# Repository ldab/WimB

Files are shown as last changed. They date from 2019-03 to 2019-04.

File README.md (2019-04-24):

# WimB - Where is my Bike

<p>The firmware has been writen using PlatformIO which is a nice, neat IDE, check it out:&nbsp;<a href="https://platformio.org/platformio-ide" rel="nofollow">Learn how to install PlatformIO IDE</a></p>







## Download Blynk App: [Getting Started with Blynk](https://www.blynk.cc/getting-started/)

This is a minimalist Blynk App you will **1,800 energy points**.

* Download Blynk App: [](http://j.mp/blynk_Android) [](http://j.mp/blynk_iOS)
* Touch the QR-code icon and point the camera to the code below


<p>
&nbsp;&nbsp;
</p>

* Enjoy my app!

## Content

1. [TODO](/README.md#TODO)
2. [How does it work?](/README.md#how-does-it-work)
3. [Estimated Power Consumption](/README.md#Estimated-Power-Consumption)
4. [Cellular data usage](/README.md#cellular-data-usage)
5. [SARA-R4 PWR_ON Pin](/README.md#SARA-R4-PWR_ON-Pin)
6. [SARA-R4 PSM - Power Save Mode configuration](/README.md#sara-r4-psm---power-save-mode-configuration)
7. [SERCOM and PIN mapping](/README.md#SERCOM-and-PIN-mapping)
8. [Schematic](/README.md#schematic)
9. [DataSheets](/README.md#datasheets)
10. [Enclosure](/README.md#enclosure)
11. [How to Start?](/README.md#how-to-start)
12. [Credits](/README.md#credits)

## TODO

- [x] Put device to sleep;
- [ ] Communnicate with SARA-R4
- [x] Set SARA-PSM values
- [ ] Communicate with GNSS;
- [ ] AssistNow AID for GNSS
- [x] Set interrupts on accelerometer;
- [x] Finish accelerometer lib
- [ ] Monitor SARA GPIO in order to detect modem is ready +UGPIOC
- [ ] Monitor SARA V_INT in order to detect modem ON
- [ ] Monitor GNSS *something* in order to detect GNSS awake

## How does it work?

Here you will find a simplified flowchart demonstrating how the code works: 

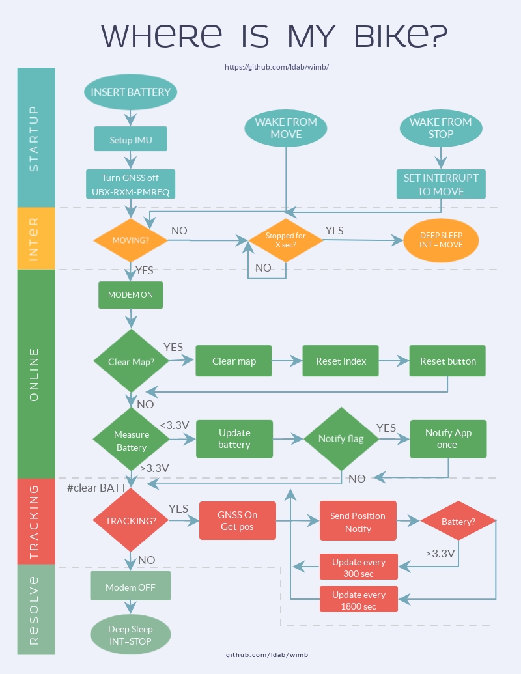
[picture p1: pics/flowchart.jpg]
Flowchart


## Estimated Power Consumption

This is hard to predict however we have the [Datasheets](./datasheet) and can roughly estimate it, we have:
* ATSAMD21E18 MCU;
* SARA-R412;
* SAM-M8Q;
* LIS3DH IMU;
* TXS0102 Level-shifter;
* SN74LVC1G07 Level-shifter;
* HT7833 LDO;
* TP4056 Battery charger;
* Battery ADC;

#### Low power - Sleeping

Arduino library set all pins as `INPUT` on `wiring.c` this result in excessive current draw, I got around 300μA on the best case scenario, turning all Clock off, VREG, and BOD33.

```
  // Setup all pins (digital and analog) in INPUT mode (default is nothing)
  for (uint32_t ul = 0 ; ul < NUM_DIGITAL_PINS ; ul++ )
  {
    pinMode( ul, INPUT ) ;
  }
```

it we change SWCLK & SWDIO to `pinMode( ul, INPUT_PULLUP ) ;` **BOOM** -> board current on sleep was spot on 48μA.

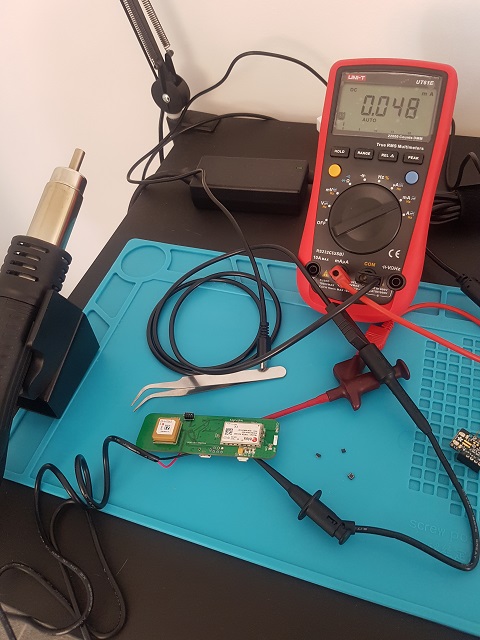
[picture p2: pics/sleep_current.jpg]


Component                 | ~TYP μA
------------------------- | ------
ATSAMD21E18 MCU           | 4
SARA-R412                 | 6
SAM-M8Q                   | 15
LIS3DH IMU                | 2
TXS0102 Level-shifter     | 2
SN74LVC1G07 Level-shifter | 5
HT7833 LDO                | Assume 10
TP4056 Battery charger    | 2
Battery ADC               | 2
TOTAL                     | 48

#### Tracking

Component                 | ~TYP μA
------------------------- | ------
ATSAMD21E18 MCU           | 4,000
SARA-R412                 | 27,200*
SAM-M8Q                   | 9,500
LIS3DH IMU                | 2
TXS0102 Level-shifter     | 14
SN74LVC1G07 Level-shifter | 5
HT7833 LDO                | Assume 10
TP4056 Battery charger    | 2
Battery ADC               | 2
TOTAL                     | ~41mA

*Current for Modem depends on the update interval, registration and signal level -> 200mA max for TX/RX @30sec to exec every 300 sec + 9mA @Active mode = 27.2mA 

## Cellular data usage

[Blynk Protocol message](https://github.com/blynkkk/blynk-server/blob/master/docs/README_FOR_APP_DEVS.md#protocol-messages)

* [Blynk HEARTBEAT](https://community.blynk.cc/t/expected-data-usage-for-hardware-connection-heartbeat-to-blynk-server/7138/16) = 5 bytes every minute;
* [Button message](https://community.blynk.cc/t/solved-gsm-data-usage/16122/2?u=ldb) = ~10 bytes
* [Data message](https://community.blynk.cc/t/blynk-electron-data-usage-extremely-high/16577/4?u=ldb) = ~14 bytes
* [TCP Overhead?](https://community.blynk.cc/t/expected-data-usage-for-hardware-connection-heartbeat-to-blynk-server/7138/16) = 20 bytes

If it connects twice a day non-active => ( Clear Map + Active? + Update Battery ) * 2 = bump it up to 80 bytes/day

Active mode running at 300 seconds => ( 5 * Heartbeat + Active? + Update Battery + Send location )* 12 = 800 bytes/hour

## SARA-R4 PWR_ON Pin

Low  level  on  the PWR_ON pin,  which  is  normally  set  high  by  an  internal  pull-up,  for  a  valid  time period  when  the applied VCCvoltage  is  within  the  valid  operating  range. The PWR_ON line has to be driven by open drain, open collector or contact switch

Parameter       |Min. |Max.  |Unit|Remarks
--------------- | --- |----- | -- | ---------------------------------------
PWR_ON low time |0.15 | 3.20 | s  | Low time to trigger module switch *ON*
PWR_ON low time |1.5  |      | s  | Low time to trigger module switch *OFF*

## SARA-R4 PSM - Power Save Mode configuration

The grant of PSM is a negotiation between SARA-R4/N4 series module and the **attached network:** the network accepts PSM  by  providing  the  actual  value  of  the  “Active  Timer”  (and  “Periodic  Update Timer”) to be used in the Attach/TAU/RAU accept procedure. The maximum duration, including the “Periodic Update Timer”, is about 413 days.  The SARA-R4/N4  series module  enters  PSM  low  power deep sleep mode only after the “Active Timer” expires

* If  the  power  saving  mode  is  enabled  (+CPSMS:  1),  everything  on  the  device  will  power  down  except  thereal-time clock (RTC) after the expiry of T3324 (Active Time). It will stay powered down until the expiry ofT3412 (Extended TAU Timer) or if the Power On line is toggled.
* If the power saving mode is disabled (+CPSMS: 0), the device will not enter Power Save Mode (PSM)

#### Requested_Periodic_TAU - PSM total duration

```
Bits 5 to 1 represent the binary coded timer value.
Bits 6 to 8 defines the timer value unit for the GPRS timer:
8 7 6 
0 0 0 value is incremented in multiples of 10 minutes
0 0 1 value is incremented in multiples of 1 hour
0 1 0 value is incremented in multiples of 10 hours
0 1 1 value is incremented in multiples of 2 seconds
1 0 0 value is incremented in multiples of 30 seconds
1 0 1 value is incremented in multiples of 1 minute
1 1 0 value is incremented in multiples of 320 hours
1 1 1 value indicates that the timer is deactivated.
```

**The requested extended periodic TAU value(T3412) iscoded as one byte (octet 3) of the GPRS Timer 3 information element coded as bitformat (e.g. "10100001" equals 1 minute).  see the GPRS Timer 3 IE in 3GPP TS 24.008 Table10.5.163a/3GPP TS 24.008 - page 669**

#### Requested_Active_Time - Active/Paging time

```
Bits 5 to 1 represent the binary coded timer value.
Bits 6 to 8 defines the timer value unit for the GPRS timer as follows:
Bits
8 7 6
0 0 0  value is incremented in multiples of 2 seconds
0 0 1  value is incremented in multiples of 1 minute
0 1 0  value is incremented in multiples of decihours
1 1 1  value indicates that the timer is deactivated.

Other values shall be interpreted as multiples of 1 minute in this version of the protocol. 
```

**Requested Active Time value (T3324) iscoded as one byte (octet 3) of the GPRS Timer 2 information element coded as bitformat (e.g. "00100100" equals 4 minutes).  see the GPRS Timer 2 IE in 3GPP TS 24.008 Table10.5.163/3GPP TS 24.008 - page 668**

## SERCOM and PIN mapping

PIN mapping and re-assignment are required since we need 3x UART and unfortunatelly Adafruit Trinket M0 did not use the same combination as we needed/wanted.

Those changes are made on the `variant.h` and `variant.cpp` found on your installation directory `.platformio\packages\framework-arduinosam\variants\trinket_m0`.

On the `.cpp` file we comment the `Serial1` definition as `SERCOM0` will be used by the I2C interface:
https://github.com/ldab/WimB/blob/5da6a90e527ac1eb7648ca4fd2846885c14b10b4/board_variant/variant.cpp#L97-L102

The `.h` file we define `SERCOM0` as the interface for I2C, as well different PIN because of `SERCOM` and `SERCOM_ALT` definition
https://github.com/ldab/WimB/blob/5da6a90e527ac1eb7648ca4fd2846885c14b10b4/board_variant/variant.h#L142-L145

## Schematic

* The Schematics provided here are provided "as it is" and no guarantee is given as it does not follow the supplier specifications especially on the antenna design:

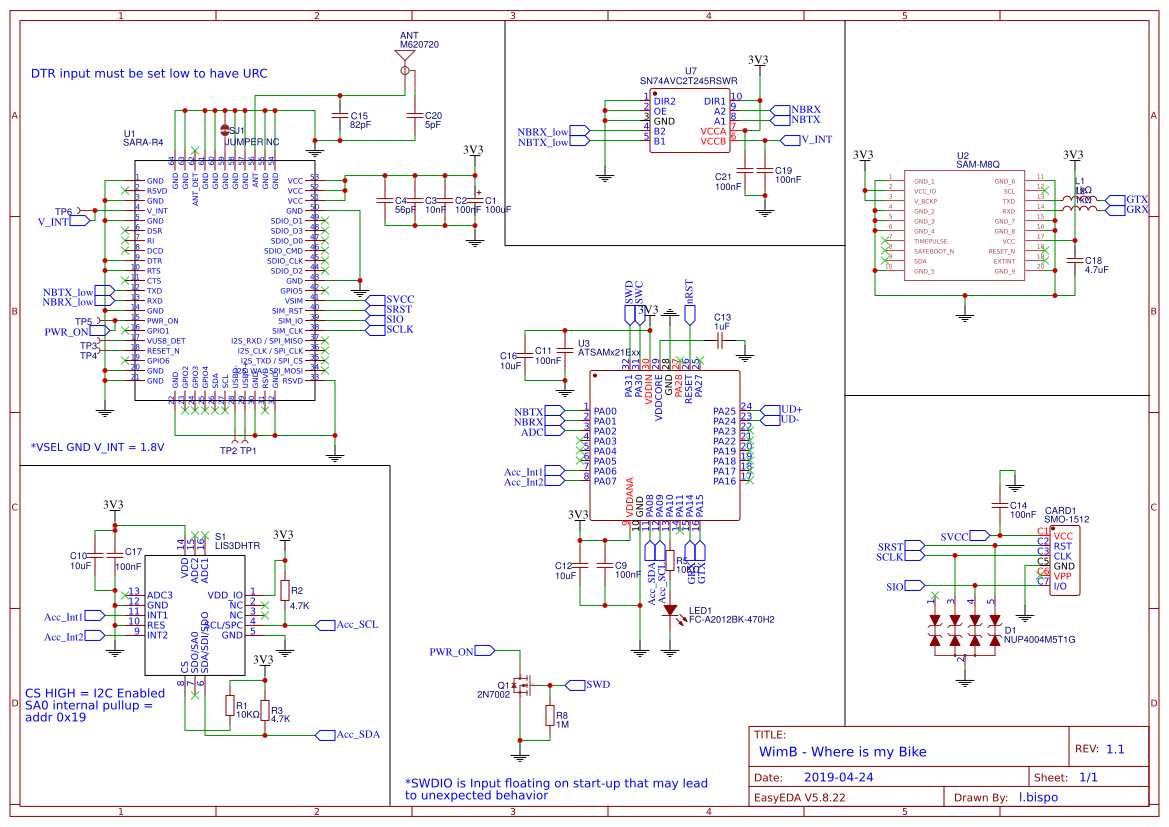
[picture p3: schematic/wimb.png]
Schematic page 1

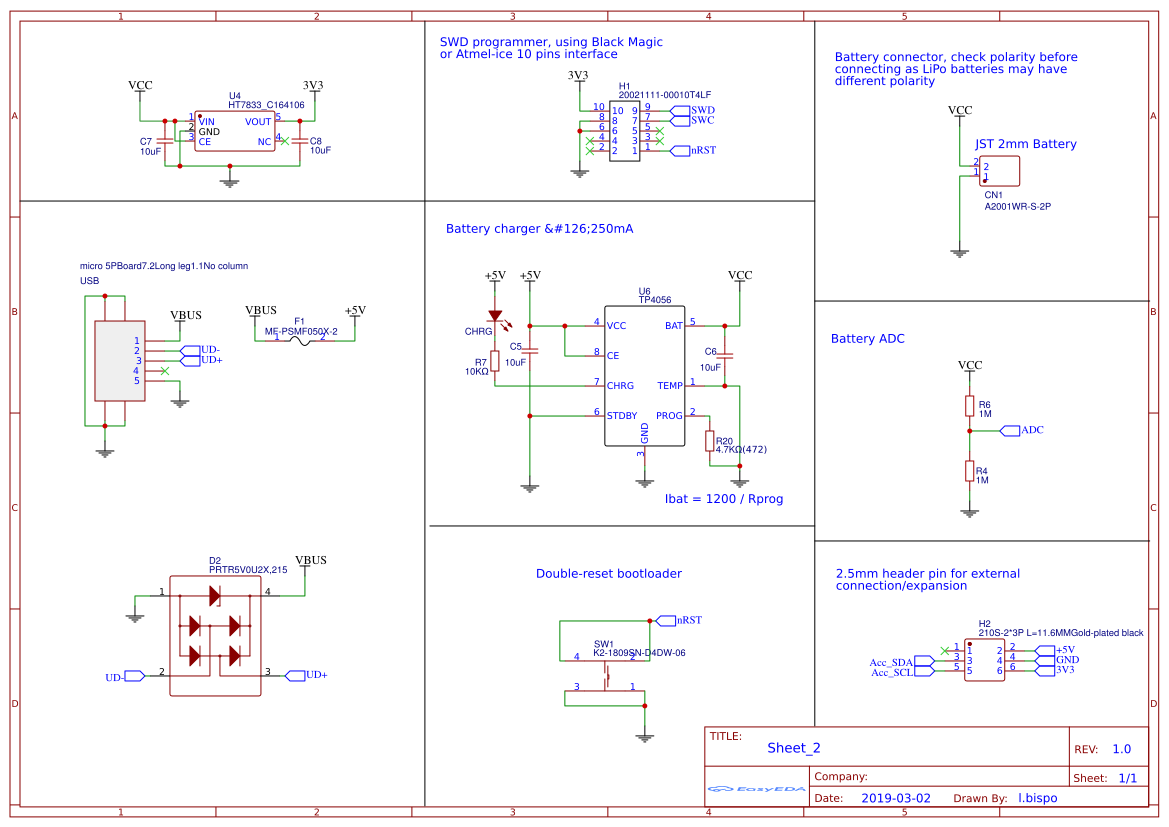
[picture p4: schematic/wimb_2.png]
Schematic page 2


## Datasheets

You can find technical information here: [datasheets](./datasheet)

## Enclosure

A 3D print file for the enclosure is also available (untestest/not printed) [here](./3DPrint%20Enclosure).

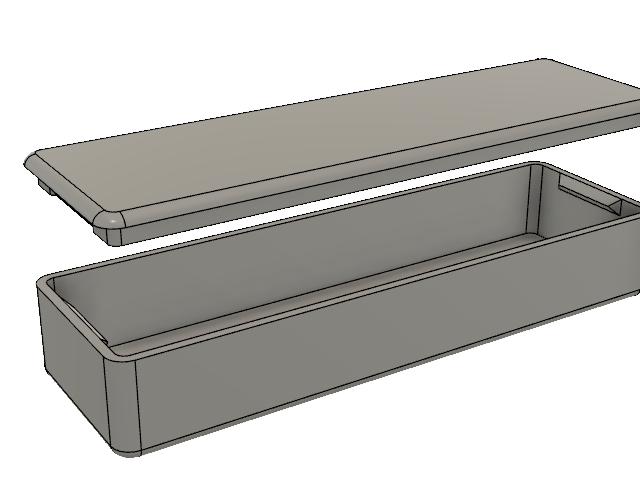
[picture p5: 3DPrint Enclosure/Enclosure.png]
enclosure


## How to start?

## Credits

Github Shields and Badges created with [Shields.io](https://github.com/badges/shields/)

Flowchart made with [VISME](https://www.visme.co/)

3D Design inspired by [Adafruit Youtube video](https://www.youtube.com/watch?v=VVmOtM60VWw) using [Autodesk Fusin 360](https://www.autodesk.com/products/fusion-360/overview)

Icons made by [Smashicons](https://www.flaticon.com/authors/smashicons) from [Flaticon](www.flaticon.com) is licensed by Creative Commons BY 3.0 [CC BY 3.0](https://creativecommons.org/licenses/by/3.0/)

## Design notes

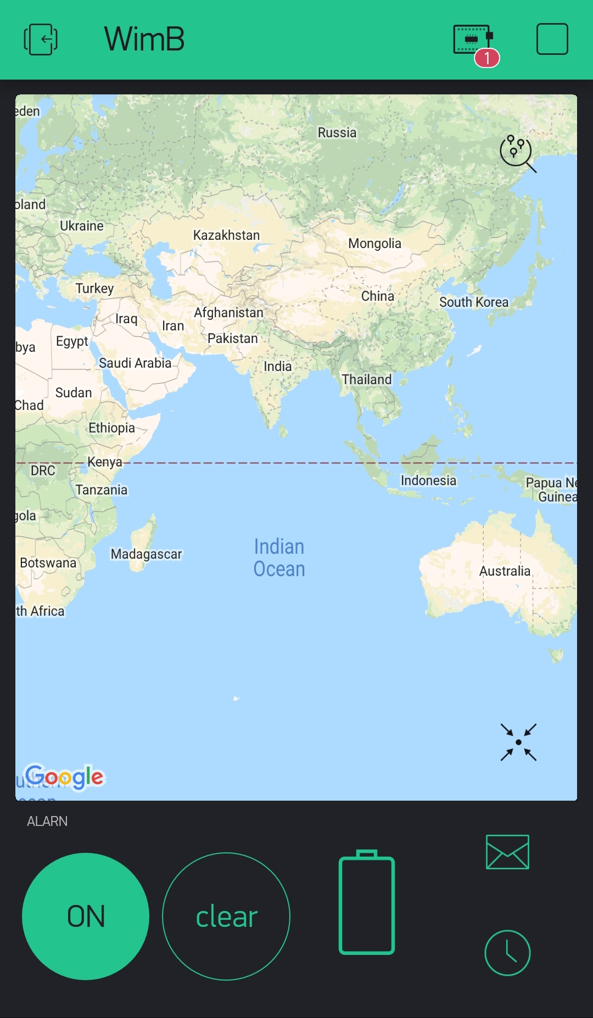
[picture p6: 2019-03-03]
pics/App_Blynk.jpg

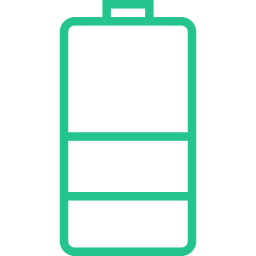
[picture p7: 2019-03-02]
pics/battery_50.png

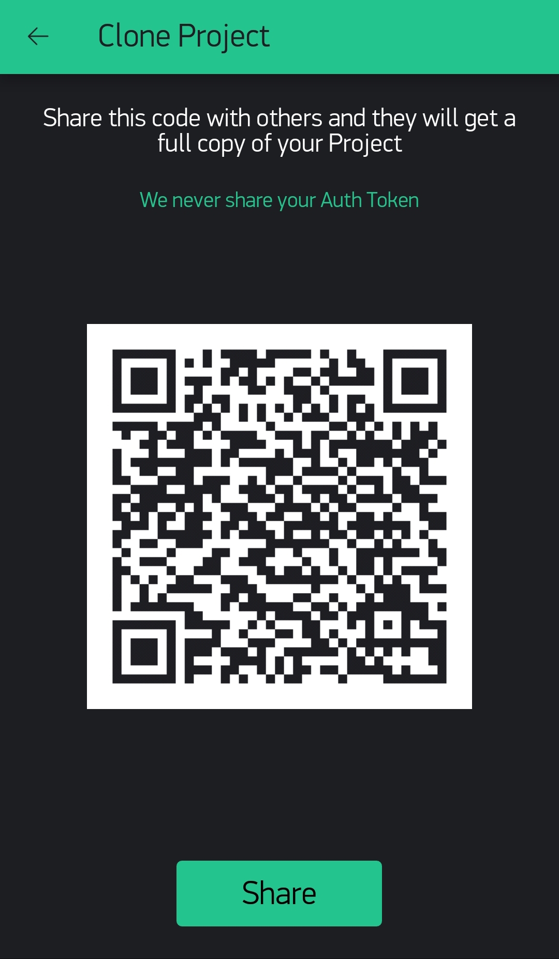
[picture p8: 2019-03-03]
pics/QR_Blynk.jpg

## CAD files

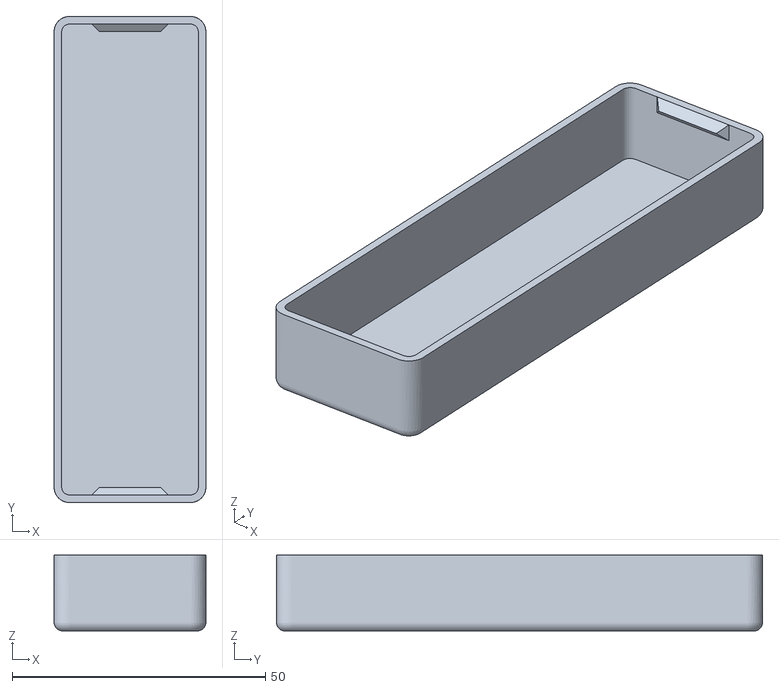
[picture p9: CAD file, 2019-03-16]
3DPrint Enclosure/case.stl
30.0 x 96.0 x 15.0

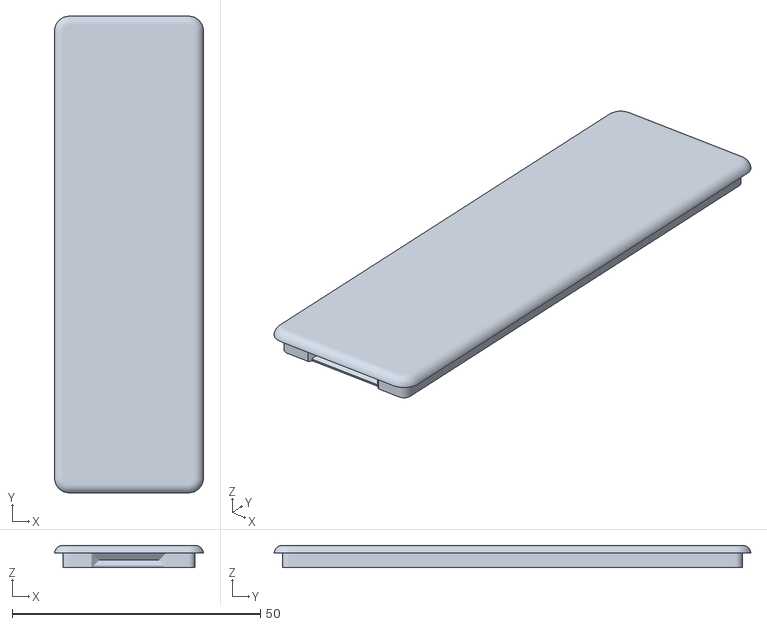
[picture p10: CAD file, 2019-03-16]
3DPrint Enclosure/cover.stl
30.0 x 96.0 x 4.50

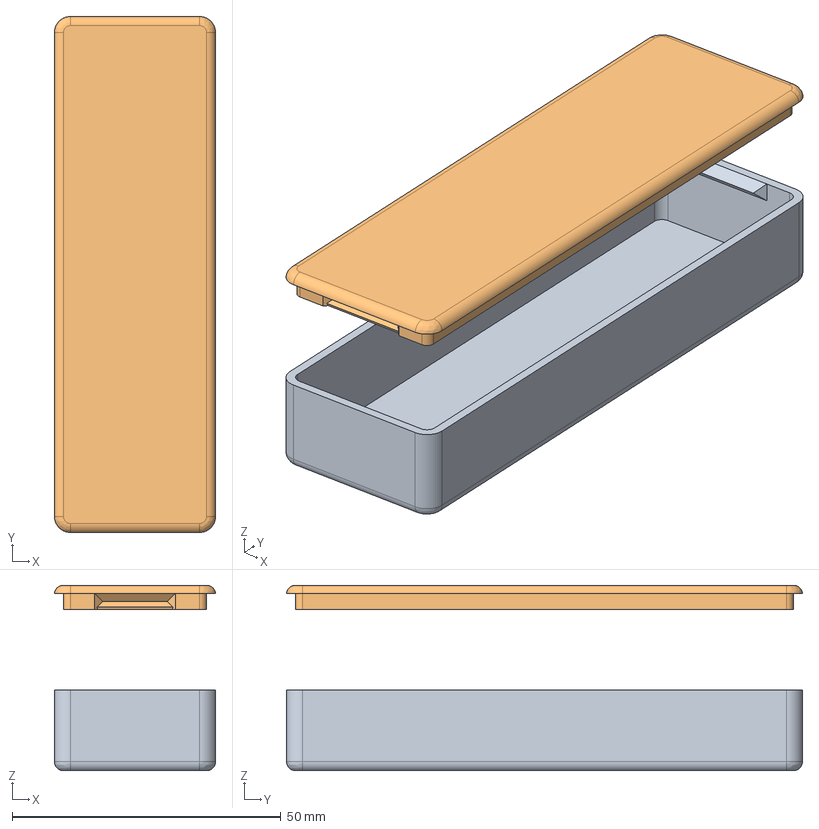
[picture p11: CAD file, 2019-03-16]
3DPrint Enclosure/Enclosure.step
30.0 x 96.0 x 34.5 mm
Case
Cover

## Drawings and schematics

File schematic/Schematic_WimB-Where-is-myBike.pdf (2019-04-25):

3V3
3V3 | 3V3

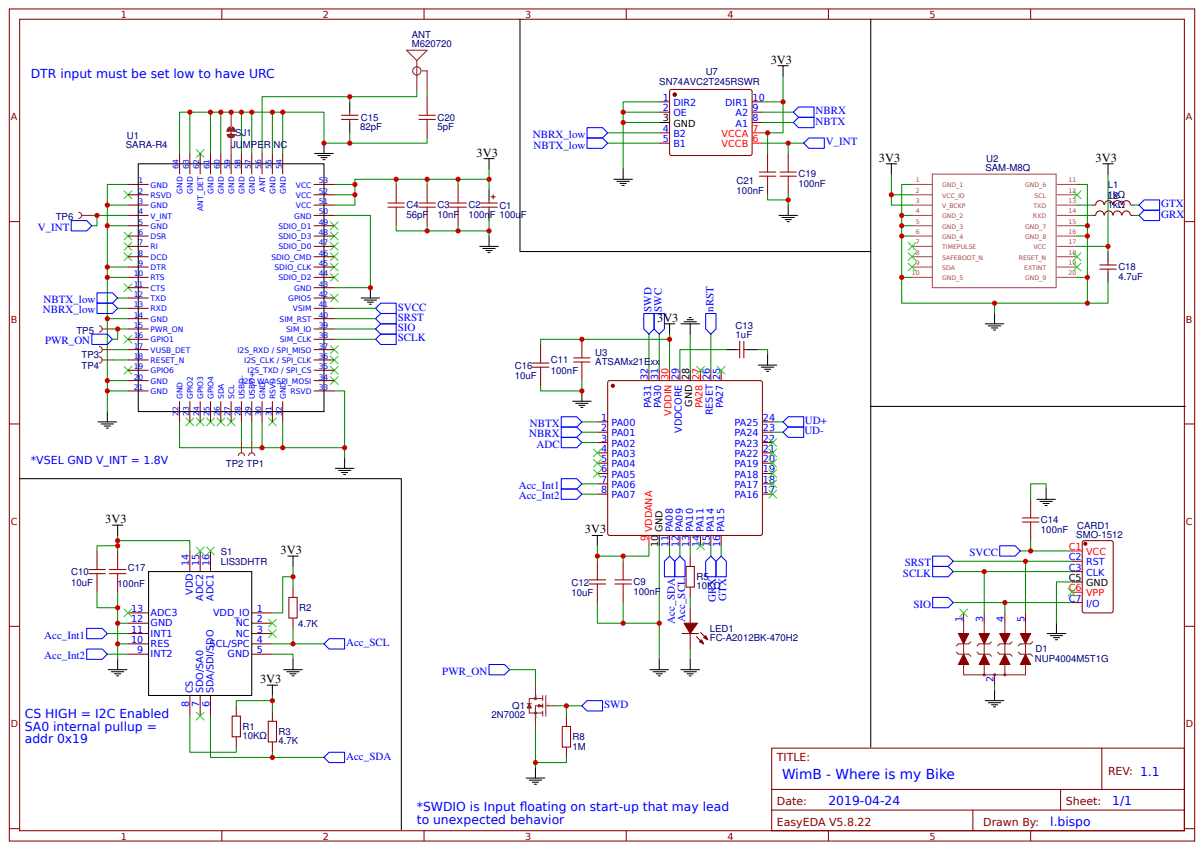
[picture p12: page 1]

RSVD 33 I2S_WA / SPI_MOSI 34 I2S_TXD / SPI_CS 35 I2S_CLK / SPI_CLK 36 I2S_RXD / SPI_MISO 37 SIM_CLK 38 SIM_IO 39 SIM_RST 40 VSIM 41 GPIO5 42 GND 43 SDIO_D2 44 SDIO_CLK 45 SDIO_CMD 46 SDIO_D0 47 SDIO_D3 48 SDIO_D1 49 GND 50 VCC 51 VCC 52 VCC 53 GND ⁵⁴ GND ⁵⁵ ANT 56 GND ⁵⁷ GND ⁵⁸

DTR input must be set low to have URC

SDA/SDI/SDO 6 SDO/SA0 7 CS 8

*SWDIO is Input floating on start-up that may lead
to unexpected behavior

3V3

### VCC

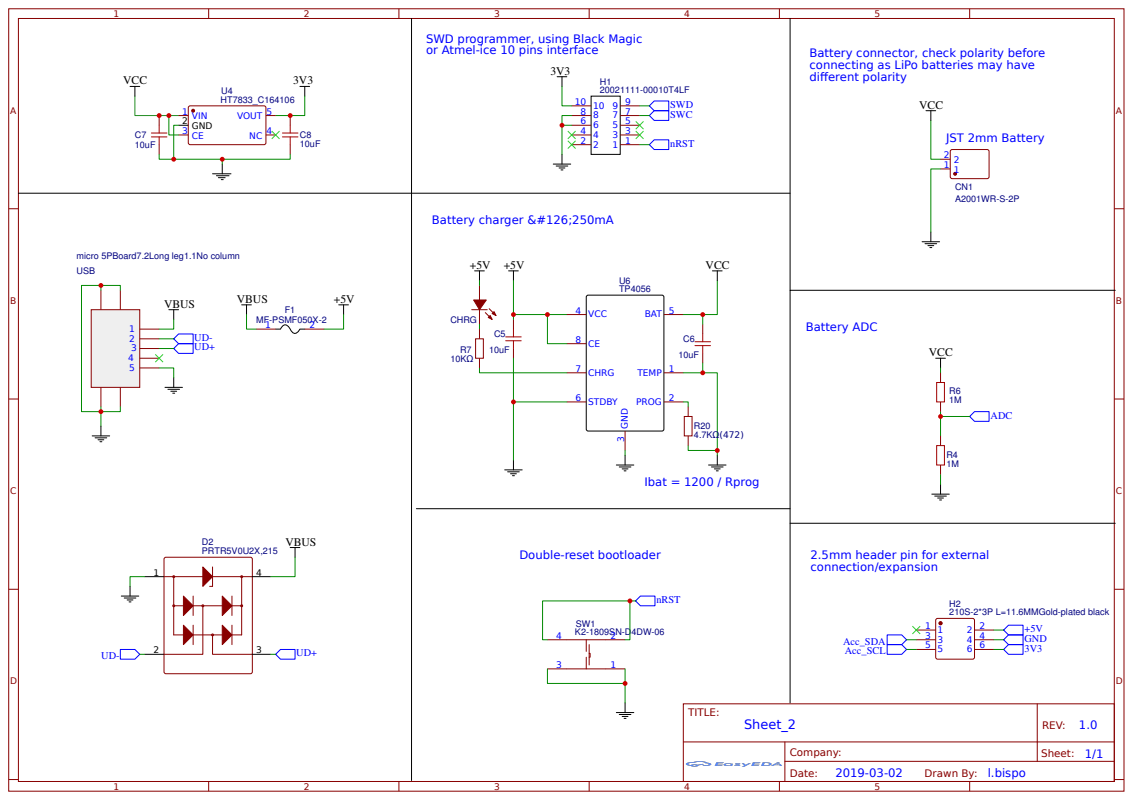
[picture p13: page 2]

SWD programmer, using Black Magic
or Atmel-ice 10 pins interface

Battery connector, check polarity before
connecting as LiPo batteries may have
different polarity

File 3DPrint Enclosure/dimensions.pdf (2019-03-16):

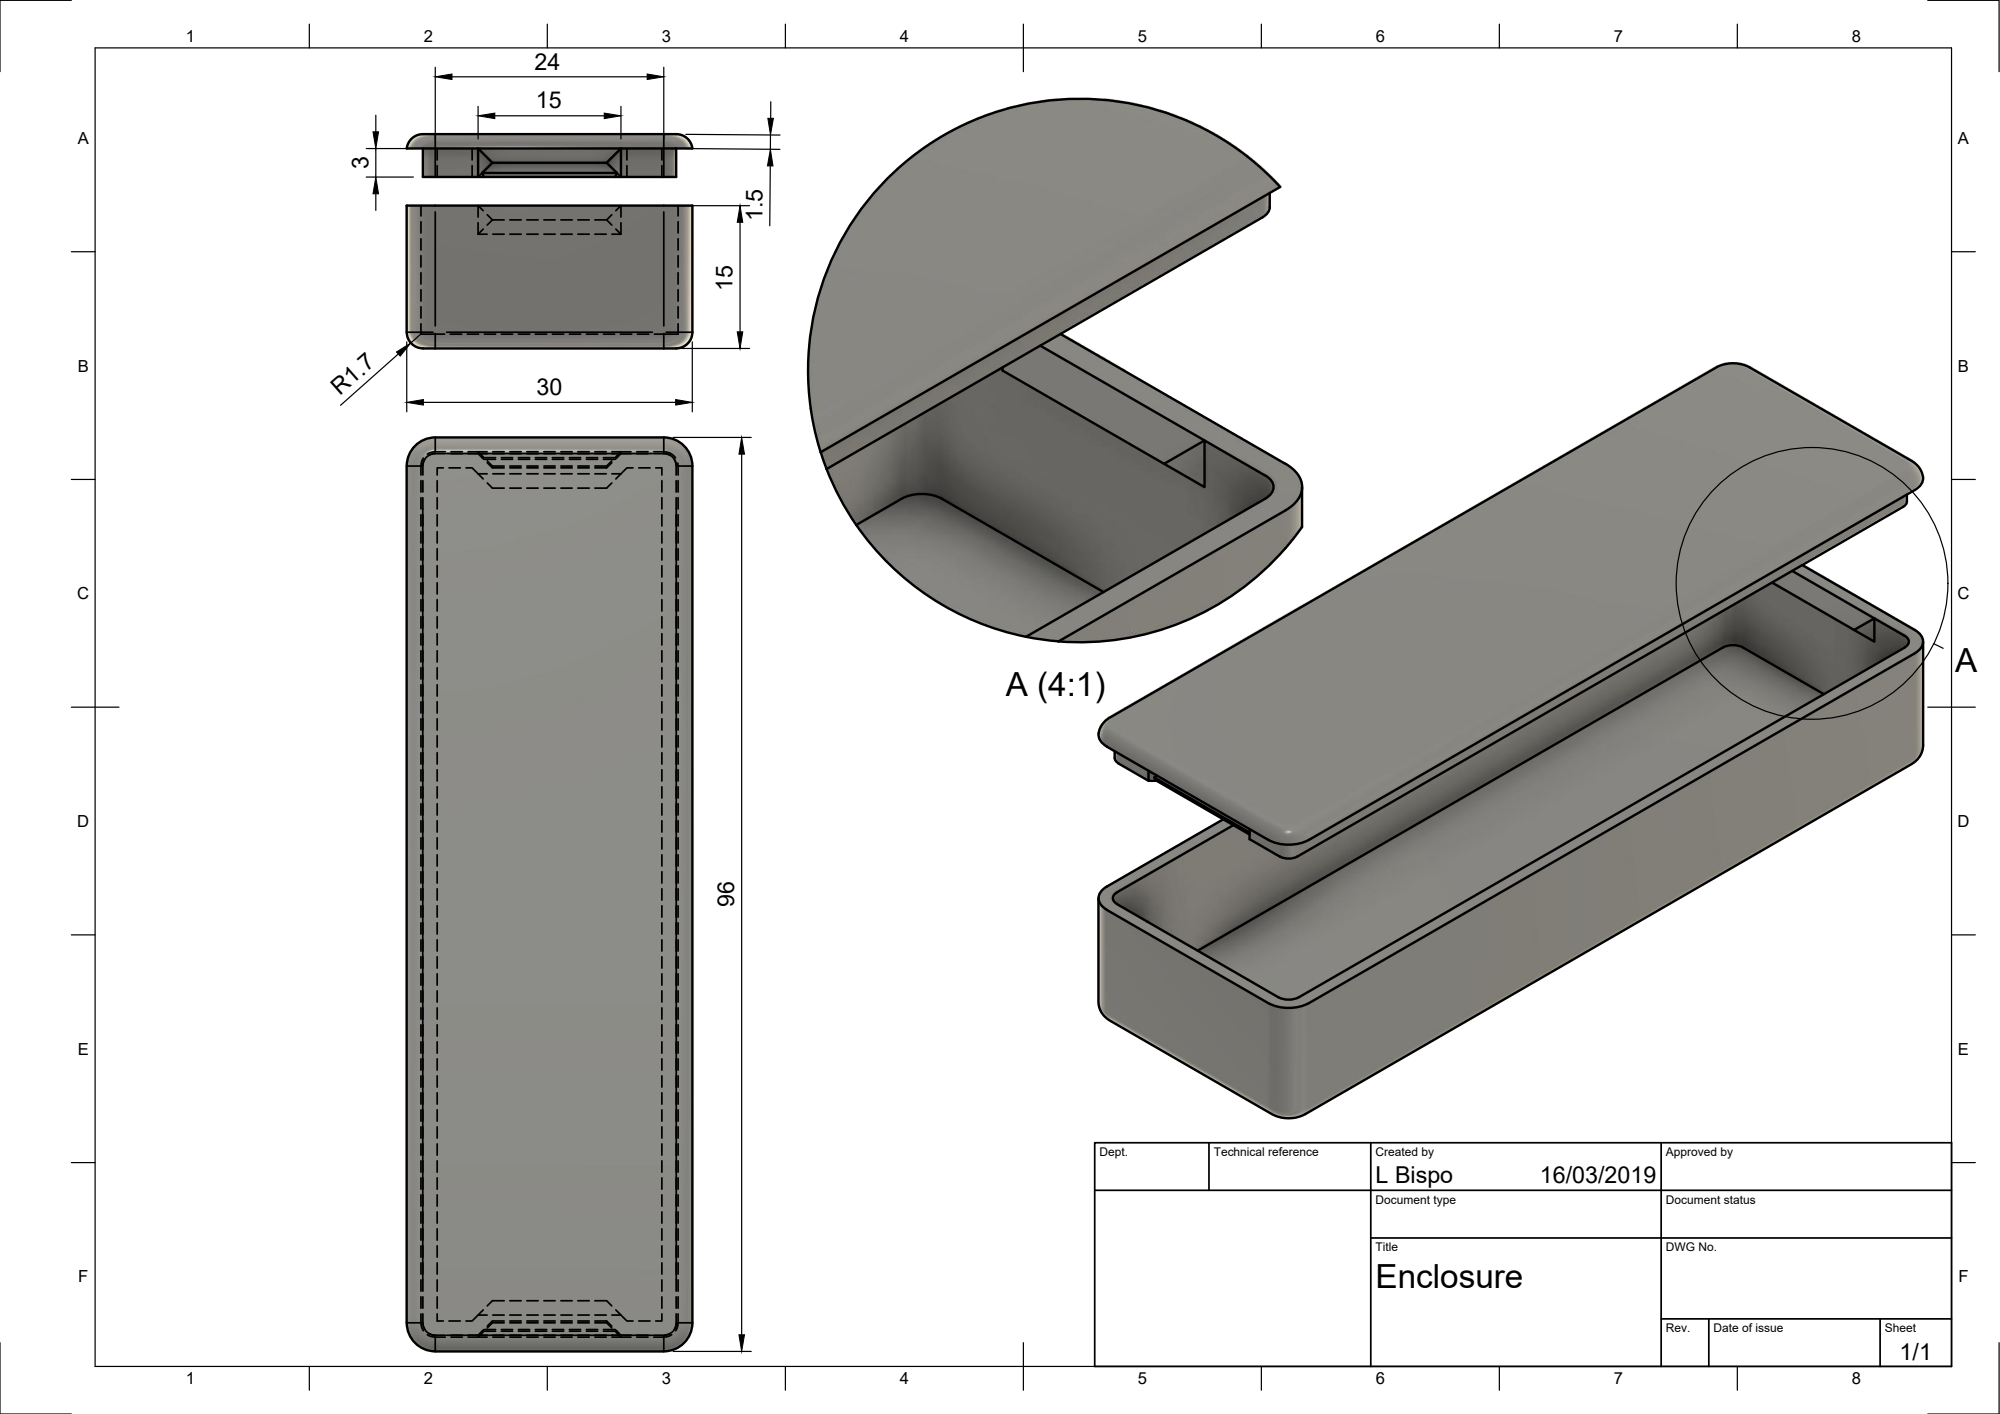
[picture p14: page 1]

Dept. | Technical reference | Created by L Bispo 16/03/2019 | Approved by

Document type | Document status

Title Enclosure | DWG No.

Rev. | Date of issue | Sheet 1/1

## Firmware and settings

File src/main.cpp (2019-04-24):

//********************************************************************************//
/*WimB - Where is my bike - Copyright (c) 2019 Leonardo Bispo.  All right reserved.
Permission is hereby granted, free of charge, to any person obtaining a copy
of this software and associated documentation files (the "Software"), to deal
in the Software without restriction, including without limitation the rights
to use, copy, modify, merge, publish, distribute, sublicense, and/or sell
copies of the Software, and to permit persons to whom the Software is
furnished to do so, subject to the following conditions:
The above copyright notice and this permission notice shall be included in all
copies or substantial portions of the Software.

THE SOFTWARE IS PROVIDED "AS IS", WITHOUT WARRANTY OF ANY KIND, EXPRESS OR
IMPLIED, INCLUDING BUT NOT LIMITED TO THE WARRANTIES OF MERCHANTABILITY,
FITNESS FOR A PARTICULAR PURPOSE AND NONINFRINGEMENT. IN NO EVENT SHALL THE
AUTHORS OR COPYRIGHT HOLDERS BE LIABLE FOR ANY CLAIM, DAMAGES OR OTHER
LIABILITY, WHETHER IN AN ACTION OF CONTRACT, TORT OR OTHERWISE, ARISING FROM,
OUT OF OR IN CONNECTION WITH THE SOFTWARE OR THE USE OR OTHER DEALINGS IN THE
SOFTWARE. */
//********************************************************************************//

#include "header.h"

// PIN re-definition
#define PIN_INT1          (18u)   // PA06
#define PIN_INT2          (17u)   // PA07
#define BATT              (14ul)  // PA02 -> A0
#define PWR_ON            (20ul)  // PA31 -> SWDIO

// ********************************************************************************//
// Change/ADD extra serial ports, SERCOM
// https://www.arduino.cc/en/Tutorial/SamdSercom
// .platformio\packages\framework-arduinosam\variants\trinket_m0
// https://github.com/ldab/wimb/variants

Uart Serial_GNSS(&sercom2, 22, 21, SERCOM_RX_PAD_3, UART_TX_PAD_2);

void SERCOM2_Handler()
{
  Serial_GNSS.IrqHandler();
}

Uart Serial_SARA(&sercom1, 8, 7, SERCOM_RX_PAD_1, UART_TX_PAD_0);

void SERCOM1_Handler()
{
  Serial_SARA.IrqHandler();
}
// ********************************************************************************//

// Your GPRS credentials
// Leave empty, if missing user or pass
const char apn[]  = "YourAPN";
const char user[] = "";
const char pass[] = "";

// You should get Auth Token in the Blynk App.
// Go to the Project Settings (nut icon).
const char auth[] = "YourAuthToken";

// Accelerometer declaration, default address is 0x19.
LIS3DH myIMU( 0x19 );

// Modem declaration, using SerialX interface.
TinyGsm modem( Serial_SARA );

// u-blox GNSS declaration
GNSS gnss( Serial_GNSS );

// Blynk declarations;
WidgetMap myMap(V0);
BlynkTimer timer;
WidgetRTC BlynkRTC;

bool batteryNotify = true;
bool moveNotify    = true;

int loc_index = 0;
int active    = 0;
int clear     = 0;

float lat, lon, batt, acc;

fixType_t fix = NO_FIX;

uint16_t  sampleRate = 1;   //Samples per second (Hz) - 1, 10, 25, 50, 100, 200, 400, 1600, 5000
uint8_t   accelRange = 2;   //Accelerometer range = 2, 4, 8, 16g

// Timers identifiers
uint8_t sendFreq = 0;

// Clear Map Pins when button is pressed
void clearMap( void );

// Put MCU to Sleep WFI -> wait for MOVE interrupt
void goodNightSTOP( void );

// Put MCU to Sleep WFI -> wait for STOP interrupt
void goodNightMOVE( void );

// WFI and DSB actually sleep command
void goToSleep( void );

// Send battery information to the App
void sendBattery( void );

// IMU detects movement for certain period of time therefore active peripherals and tracking
void onlineMode( void );

// Get coordinates function as timer requires void
void getCoordinates( void );

// Request Blynk server to re-send latest values for all pins in case hardware reset or 
// lose input status and to allow Clear command when hardware is offline/sleeping
BLYNK_CONNECTED() 
{
  Blynk.syncVirtual(V2, V3, V10);
}

BLYNK_WRITE(V2)
{
  active = param.asInt();
  if( active )
  {
    Serial_GNSS.begin( 9600 );
    
    // Initialize GNSS, interval mode, 280sec Off and 10sec active.
    gnss.init( ON_OFF, 280000, 10);
    
    if( moveNotify )
    {
      String emailBody = String("<p>Asset is moving, check the app for location.</p><p>Battery = ")
                               + String(batt,2) + "V.</p>";
      Blynk.email("🚨 Asset Moving 🏃", emailBody);
      moveNotify = false;      
    }

    getCoordinates();
    sendFreq = timer.setInterval(60000L, getCoordinates);
  }
  else
  {
    // Disable motion detection until next STOP -> Interrupt 2
    moveNotify = true;
    goodNightMOVE();
  }
  
}

BLYNK_WRITE(V3)
{
  clear = param.asInt();

  if(clear) clearMap();

  sendBattery();
}

BLYNK_WRITE(V10) 
{
  // Use Blynk Cloud to keep track of location index
  // TODO may need to compare with internal memory, check def behaviour on atsamd21e18
  loc_index = param.asInt();
}

void getCoordinates()
{
  if( gnss.getCoodinates(lon, lat, fix, acc, 50) )
  {
    String dateTime = String(day()) + "/" + month() + "-" + hour() + ":" + minute();
    myMap.location(loc_index, lat, lon, dateTime);
    loc_index++;
  }
  // Keep track of battery and change frequency if low
  sendBattery();
  if( !batteryNotify )
    timer.changeInterval(sendFreq, 300000L);
}

void sendBattery()
{
  // Measure few times in order to smooth it out
  batt = 0;
  for( int i=0; i<10; i++)
  {
    batt += float(analogRead(BATT))*2.23f / 4095 * 2; //calculate battery considerin 1M voltage divider and 12 bits
  }

  batt /= 10.0f;

  // TODO - Battery levels to be defined;
  // currently based on https://github.com/ldab/WimB/blob/master/datasheet/GMB052030.pdf
  if( batt > 3.8 ){
      Blynk.virtualWrite(V4, 4);
      batteryNotify = true;
  }
  else if( batt > 3.6 ){
      Blynk.virtualWrite(V4, 3);
  }
  else if( batt > 3.5 ){
      Blynk.virtualWrite(V4, 2);
  }
  else{
      Blynk.virtualWrite(V4, 1);
      if( batteryNotify )
      {
        String emailBody = String("Battery is running low @") + String(batt,2) + "V charge it.";
        Blynk.email("🚨 Low Battery 🔌", emailBody);
        batteryNotify = false;
      }
  }
}

void clearMap()
{
  myMap.clear();
  loc_index = 0;
  Blynk.virtualWrite(V3, 0);
}

void goodNightSTOP()
{
  // Remove interrupt from stop to avoid multiple wakes, this PIN will be High when not moving
  detachInterrupt(INT_2);
  attachInterrupt(INT_1, onlineMode, HIGH); // Sanity check
  delay(20);

  goToSleep();
}

void goodNightMOVE()
{
  // Turn SARA modem off
  digitalWrite(PWR_ON, HIGH);
  delay(1600);
  digitalWrite(PWR_ON, LOW);

  // Remove interrupt from start to avoid multiple wakes, HIGH = not moving
  detachInterrupt(INT_1);
  attachInterrupt(INT_2, goodNightSTOP, HIGH); // Sanity check
  delay(20);

  goToSleep();
}

void setup()
{
    /************************************************************************
  * \.platformio\packages\framework-arduinosam\cores\adafruit\wiring.c
  * Line 107 -> INPUT_PULLUP reduces the current significantly
  * SWCLK when Pulled UP reduces the sleep current               
  * ***********************************************************************/
  pinMode( 19, INPUT_PULLUP );

  // Control SARA Module
  pinMode(PWR_ON, OUTPUT);
  digitalWrite(PWR_ON, LOW);
  
  // Set console baud rate
  Serial.begin(115200);
  delay(10);

  BlynkRTC.begin();

  // The default analogRead() resolution for these boards is 10 bits, for compatibility.
  analogReadResolution(12);
  analogReference(AR_INTERNAL2V23);                // Change reference to internal 2.23V
  pinMode(BATT, INPUT);                            // Battery connected to PA02
  batt = float(analogRead( BATT )) * 2.23f / 4095 * 2; // Calculate battery considerin 1M voltage divider and 12 bits

  if( myIMU.begin(sampleRate, 1, 1, 1, accelRange) != 0 )
  {
    Serial.print("Failed to initialize IMU.\n");
  }

  //Detection threshold can be from 1 to 127 and depends on the Range chosen above, change it and 
  //test accordingly to your application -> Duration = timeDur x Seconds / sampleRate
  myIMU.intConf(INT_1, DET_MOVE, 3, 5);
  myIMU.intConf(INT_2, DET_STOP, 1, 30);

  //Confirm configuration,
  // !!! POWER reset is required in order to ssave IMU Config
  uint8_t readData = 0;
  myIMU.readRegister(&readData, LIS3DH_INT1_CFG);
  myIMU.readRegister(&readData, LIS3DH_INT2_CFG);

  // map PINs to SERCOM ALT for SARA UART
  pinPeripheral(7, PIO_SERCOM_ALT);
  pinPeripheral(8, PIO_SERCOM_ALT);

  // Initialize GNSS UART
  pinPeripheral(21, PIO_SERCOM);
  pinPeripheral(22, PIO_SERCOM);

  Serial_GNSS.begin(9600);
  delay(10);

  // Initialize GNSS on a silly number just to make it sleep in case it wakes as we're not monitoring it
  gnss.init( ON_OFF, 36000, 5);

  // When power reset GNSS auto goes on, turn it off;
  gnss.off();

  // Interrupt 1 to detect when it's moving -> PA00 pin 8
  pinMode(PIN_INT1, INPUT);
  attachInterrupt(PIN_INT1, onlineMode, HIGH);

  // Interrupt 2 to detect when it's stopped -> PA01 pin 7
  pinMode(PIN_INT2, INPUT);
  attachInterrupt(PIN_INT2, goodNightSTOP, HIGH);

}

void loop()
{
  Blynk.run();
  timer.run();
}

void onlineMode()
{
  // Initialize GSM SARA module
  Serial_SARA.begin( 115200 );
  //delay(3000);
  delay(10);

  //Toggle POWER ON Pin for 0.3 seconds to turn module ON
  digitalWrite(PWR_ON, HIGH);
  delay(300);
  digitalWrite(PWR_ON, LOW);
  delay(2000); // alow few seconds for modem to turn ON
  
  // Initialize modem as restart had many invalid parameters for R412
  Serial.println("Initializing modem...");
  modem.init();

  // TinyGSM Lib does not use the right APN set@ https://github.com/vshymanskyy/TinyGSM/issues/244
  //char apnConfig[] = "AT+CGDCONT=1,\"IP\",\"";
  //strcat (apnConfig, apn);
  //strcat (apnConfig, "\"");
  //Serial_SARA.write(apnConfig);
  // TODO check reply

  String modemInfo = modem.getModemInfo();
  Serial.print("Modem: ");
  Serial.println(modemInfo);

  // Unlock your SIM card with a PIN
  //modem.simUnlock("1234");

  Blynk.config(modem, auth);
  //Blynk.begin(auth, modem, apn, user, pass);

  detachInterrupt(PIN_INT1);

}

void goToSleep()
{
    // 15.8.3 Generic Clock Control - http://ww1.microchip.com/downloads/en/DeviceDoc/SAMD21-Family-DataSheet-DS40001882D.pdf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
  GCLK->CLKCTRL.reg |= GCLK_CLKCTRL_ID( GCM_EIC ) |   // EIC id for the external interrupt controller
                       GCLK_CLKCTRL_GEN_GCLK2     |   // generic clock 2 which is OSCULP32K
                       GCLK_CLKCTRL_CLKEN;            // enable it

  while (GCLK->STATUS.bit.SYNCBUSY);                  // Write protected, wait for sync

  // Make sure that the Flash does not power all the way down https://github.com/arduino-libraries/ArduinoLowPower/blob/b38a5bc50c06da903f6614f773d2a676203c7bf2/src/samd/ArduinoLowPower.cpp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
  NVMCTRL->CTRLB.bit.SLEEPPRM = NVMCTRL_CTRLB_SLEEPPRM_DISABLED_Val;
  
  // Set Standby mode (OR Idle) http://infocenter.arm.com/help/topic/com.arm.doc.dui0662b/DUI0662B_cortex_m0p_r0p1_dgug.pdf#G7.1046307
  SCB->SCR |= SCB_SCR_SLEEPDEEP_Msk;

  Serial.end();
  Serial_GNSS.end();
  Serial_SARA.end();
  
  USBDevice.detach();

  __DSB();
  __WFI();

  USBDevice.attach();

  //Serial.begin( 115200 );
  //Serial_SARA.begin( 115200 );
  //Serial_GNSS.begin( 9600 );

}

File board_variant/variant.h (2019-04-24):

/*
  Copyright (c) 2014-2015 Arduino LLC.  All right reserved.

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
  You should have received a copy of the GNU Lesser General Public
  License along with this library; if not, write to the Free Software
  Foundation, Inc., 51 Franklin St, Fifth Floor, Boston, MA  02110-1301  USA
*/

#ifndef _VARIANT_ARDUINO_ZERO_
#define _VARIANT_ARDUINO_ZERO_

// The definitions here needs a SAMD core >=1.6.6
#define ARDUINO_SAMD_VARIANT_COMPLIANCE 10606

/*----------------------------------------------------------------------------
 *        Definitions
 *----------------------------------------------------------------------------*/

/** Frequency of the board main oscillator */
#define VARIANT_MAINOSC		(32768ul)

/** Master clock frequency */
#define VARIANT_MCK			  (48000000ul)

/*----------------------------------------------------------------------------
 *        Headers
 *----------------------------------------------------------------------------*/

#include "WVariant.h"

#ifdef __cplusplus
#include "SERCOM.h"
#include "Uart.h"
#endif // __cplusplus

#ifdef __cplusplus
extern "C"
{
#endif // __cplusplus

/*----------------------------------------------------------------------------
 *        Pins
 *----------------------------------------------------------------------------*/

// Number of pins defined in PinDescription array
#define PINS_COUNT           (22u)
#define NUM_DIGITAL_PINS     (22u)
#define NUM_ANALOG_INPUTS    (5u)
#define NUM_ANALOG_OUTPUTS   (1u)
#define analogInputToDigitalPin(p)  ((p < 5u) ? (p) + PIN_A0 : -1)

#define digitalPinToPort(P)        ( &(PORT->Group[g_APinDescription[P].ulPort]) )
#define digitalPinToBitMask(P)     ( 1 << g_APinDescription[P].ulPin )
//#define analogInPinToBit(P)        ( )
#define portOutputRegister(port)   ( &(port->OUT.reg) )
#define portInputRegister(port)    ( &(port->IN.reg) )
#define portModeRegister(port)     ( &(port->DIR.reg) )
#define digitalPinHasPWM(P)        ( g_APinDescription[P].ulPWMChannel != NOT_ON_PWM || g_APinDescription[P].ulTCChannel != NOT_ON_TIMER )

/*
 * digitalPinToTimer(..) is AVR-specific and is not defined for SAMD
 * architecture. If you need to check if a pin supports PWM you must
 * use digitalPinHasPWM(..).
 *
 * https://github.com/arduino/Arduino/issues/1833
 */
// #define digitalPinToTimer(P)

// LEDs
#define PIN_LED_13           (13u)
#define PIN_LED_RXL          (21u)
#define PIN_LED_TXL          (22u)
#define PIN_LED              PIN_LED_13
#define PIN_LED2             PIN_LED_RXL
#define PIN_LED3             PIN_LED_TXL
#define LED_BUILTIN          PIN_LED_13
// DotStar LED
#define INTERNAL_DS_DATA     7
#define INTERNAL_DS_CLK      8

/*
 * Analog pins
 */
#define PIN_A0               (14ul)
#define PIN_A1               (PIN_A0 + 1)
#define PIN_A2               (PIN_A0 + 2)
#define PIN_A3               (PIN_A0 + 3)
#define PIN_A4               (PIN_A0 + 4)
#define PIN_DAC0             PIN_A0

static const uint8_t A0  = PIN_A0;
static const uint8_t A1  = PIN_A1;
static const uint8_t A2  = PIN_A2;
static const uint8_t A3  = PIN_A3;
static const uint8_t A4  = PIN_A4;
static const uint8_t DAC0 = PIN_DAC0;

#define ADC_RESOLUTION		12

/*
 * Serial interfaces
 */

// Serial1 (sercom 0)
#define PIN_SERIAL1_RX       (3ul) // PA07
#define PAD_SERIAL1_RX       (SERCOM_RX_PAD_3)
#define PIN_SERIAL1_TX       (4ul) // PA06
#define PAD_SERIAL1_TX       (UART_TX_PAD_2)

/*
 * SPI Interfaces
 */
#define SPI_INTERFACES_COUNT 1 // shared with I2C/UART (can't do both)

#define PIN_SPI_MISO         (6u)  // PA09 same as D2
#define PIN_SPI_MOSI         (4u)
#define PIN_SPI_SCK          (3u)
#define PERIPH_SPI           sercom0
#define PAD_SPI_TX           SPI_PAD_2_SCK_3
#define PAD_SPI_RX           SERCOM_RX_PAD_1

static const uint8_t SS	  = 5 ;	// SERCOM0 last PAD is present on 5 but HW SS isn't used. Set here only for reference.
static const uint8_t MOSI = PIN_SPI_MOSI ;
static const uint8_t MISO = PIN_SPI_MISO ;
static const uint8_t SCK  = PIN_SPI_SCK ;

/*
 * Wire Interfaces
 */
#define WIRE_INTERFACES_COUNT 1

#define PIN_WIRE_SDA         (5u)
#define PIN_WIRE_SCL         (6u)
#define PERIPH_WIRE          sercom0
#define WIRE_IT_HANDLER      SERCOM0_Handler

static const uint8_t SDA = PIN_WIRE_SDA;
static const uint8_t SCL = PIN_WIRE_SCL;

/*
 * USB
 */
#define PIN_USB_HOST_ENABLE (9ul)
#define PIN_USB_DM          (10ul)
#define PIN_USB_DP          (11ul)

#ifdef __cplusplus
}
#endif

/*----------------------------------------------------------------------------
 *        Arduino objects - C++ only
 *----------------------------------------------------------------------------*/

#ifdef __cplusplus

/*	=========================
 *	===== SERCOM DEFINITION
 *	=========================
*/
extern SERCOM sercom0;
extern SERCOM sercom1;
extern SERCOM sercom2;
extern SERCOM sercom3;

extern Uart Serial1;

#endif

// These serial port names are intended to allow libraries and architecture-neutral
// sketches to automatically default to the correct port name for a particular type
// of use.  For example, a GPS module would normally connect to SERIAL_PORT_HARDWARE_OPEN,
// the first hardware serial port whose RX/TX pins are not dedicated to another use.
//
// SERIAL_PORT_MONITOR        Port which normally prints to the Arduino Serial Monitor
//
// SERIAL_PORT_USBVIRTUAL     Port which is USB virtual serial
//
// SERIAL_PORT_LINUXBRIDGE    Port which connects to a Linux system via Bridge library
//
// SERIAL_PORT_HARDWARE       Hardware serial port, physical RX & TX pins.
//
// SERIAL_PORT_HARDWARE_OPEN  Hardware serial ports which are open for use.  Their RX & TX
//                            pins are NOT connected to anything by default.
#define SERIAL_PORT_USBVIRTUAL      Serial
#define SERIAL_PORT_MONITOR         Serial
// Serial has no physical pins broken out, so it's not listed as HARDWARE port
#define SERIAL_PORT_HARDWARE        Serial1
#define SERIAL_PORT_HARDWARE_OPEN   Serial1

#endif /* _VARIANT_ARDUINO_ZERO_ */

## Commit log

2019-03-02 new battery pics
2019-03-02 update battery pics and README
2019-03-07 fix board on travis
2019-03-09 Fix Interrupt name - Stop travis
    [main.cpp]
2019-03-16 alpha version - Untested but compiles
    [Enclosure.step, case.stl, cover.stl]
2019-03-17 now sending coordinates, add bluepill as na option (crashes)
    [main.cpp]
2019-04-06 Initial 65uA test -> Hardware to be fixed *Checkpoint
    [main.cpp, sleepmode_test.cpp, variant.cpp]
2019-04-24 new board variants accordingly to the latest schematic, trying to keep as close as possible to the original
2019-04-24 PIN assignment to match new schematic
2019-04-25 update schematic

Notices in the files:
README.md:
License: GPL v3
